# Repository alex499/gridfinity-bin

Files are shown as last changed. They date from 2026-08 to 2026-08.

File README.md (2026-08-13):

**English** · [Русский](README.ru.md)

# gridfinity-bin

A parametric [Gridfinity](https://gridfinity.xyz/) bin generator written from scratch in
OpenSCAD, with no external libraries.

**[Configure one in your browser →](https://alex499.github.io/gridfinity-bin/)** — no
install, no account. The page runs this same `gridfinity.scad` through OpenSCAD compiled to
WebAssembly, so the STL it hands you is the one the command line would produce.

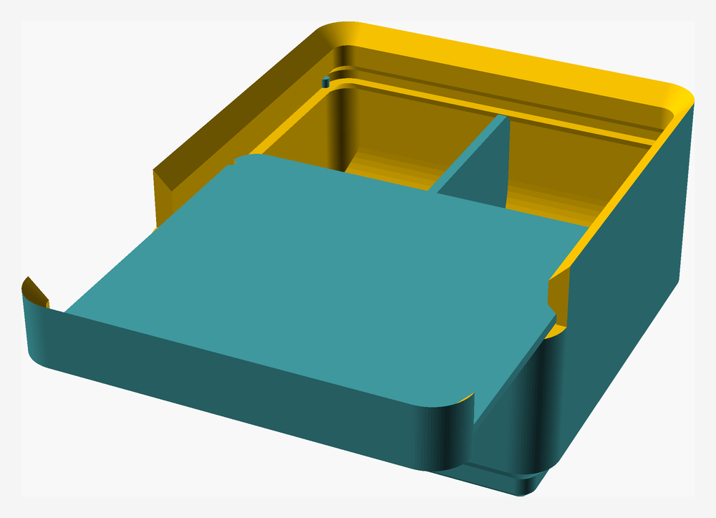
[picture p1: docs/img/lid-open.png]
A 1x1x3 bin with a two-by-two cell grid, its lid slid halfway out


*A 1x1x3 bin with `cells = 4`, its lid halfway out —
[open this one in the configurator](https://alex499.github.io/gridfinity-bin/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).
Every picture on this page is rendered from this file by
[scripts/render-images.sh](scripts/render-images.sh).*

This project is a compilation of three existing Gridfinity bin designs — it takes the
features of each and reimplements them as a single parametric model driven by the
OpenSCAD Customizer:

- [Gridfinity Bins medium size](https://www.printables.com/model/710839-gridfinity-bins-medium-size) by Plastic Flow
- [Gridfinity UltraLight Bins – Modular Clip-On Label System](https://www.printables.com/model/1481418-gridfinity-ultra-light-bins-modular-clip-on-label) by Muad'Dib
- [Gridfinity inserts with cover, divided in multiple ways](https://www.printables.com/model/665798) by mhejjas

The geometry was matched against the published STLs by measuring their cross-sections,
rather than by converting or editing the meshes. The scoop, for example, is a concave
fillet of radius 10 mm, tangent to both the inner front wall and the cavity floor —
numbers taken from the ultra-light bin's actual profile. Where the sources disagree
with the official Gridfinity dimensions, the spec wins: the stacking lip is built to
spec rather than copied from any of them.

## What is implemented

- Outer shell sized to the Gridfinity grid (42 mm pitch, 7 mm height unit) with rounded
  corners. Total height is `units_z * 7 + 4.4` mm, measured from the bottom of the feet —
  the feet are part of the height unit, not added on top of it
- Hollow interior with independent wall and floor thickness
- Full Gridfinity foot profile (0.8 mm chamfer / 1.8 mm vertical / 2.15 mm chamfer)
- Hollow feet, so the cavity extends down into the base and only a thin bottom skin
  remains — the "ultra light, no magnets" approach. The cavity inside a foot is a single
  taper rather than a copy of the stepped outer profile: less plastic and no horizontal
  overhang ledges to print
- Optional scoop: a concave fillet in the floor-to-front-wall corner, added as material
  inside the cavity, so its radius is never limited by wall or floor thickness
- Stacking lip to spec (0.7 / 1.8 / 1.9 mm, 4.4 mm total). Its bottom chamfer is derived
  from the wall thickness instead of being hard-coded: the spec's 0.7 mm assumes a 1.2 mm
  wall, and a thinner wall needs a longer run to avoid an unsupported ledge. With a plate
  under it that run starts lower still, so the same cone doubles as the slot's ceiling
- Optional flush front wall, padding the scoop side out to the lip's inner face so a
  swept-out part meets no ledge on the way to the rim
- A slot just under the lip that a closing plate slides into: the wall thickens 1.2 mm
  through a 45° ramp and steps back, and the step is the ledge the plate rests on. Nothing
  is built above it — the lip's own support cone is lowered onto the ceiling of the slot
  and is what holds the plate down. A round pin sunk into each side wall stands proud of it
  and the plate's edge snaps over it into a matching seat — 0.59 mm under a lid, 0.9 mm
  under a card, which is short and has nothing else gripping it
- Two plates use that slot, and `closure` picks between them. One is the clip-on label card,
  15 mm deep by default. The other is a **sliding lid** covering the whole bin. Same
  thickness, same ledge, same detents; the lid adds a tab that fills the mouth and restores
  the piece of lip it cut away, so a closed bin still stacks. Printed flat, the lid has no
  downward-facing face at all. On `auto` the bin decides for itself — card while it is
  undivided, lid once it is not, because a lid is the only thing that keeps contents from
  crossing between cells — but either plate can be asked for outright, and `none` leaves
  the bin open with no slot cut at all
- `split_lid` cuts the lid on the dividers between cells, one piece per cell, so a cell can
  be opened without pulling the whole lid off. Each piece slides into its own column through
  the same mouth and carries its slice of the tab. The divider under a seam becomes a rail
  and holds the two pieces on it the way a wall holds their outer edges: 1.2 mm of ledge
  under each edge, a cap 0.5 mm thick over it, and 45° flares into both so neither overhang
  needs support. The cap tops out level with the lid rather than with the rim, and the edge
  under it is chamfered on the same 45° to nest below it, so the closed lid is flat — nothing
  of the rail stands above it. The rail carries the same detent the walls do, one in each of
  its two grooves, so every piece snaps over a pair of pins just as the whole lid snaps over
  the pair in the walls. With two rows the bin gets a second mouth, in the back wall, so each
  row slides in from its own end — which is why a rail lying across the bin can keep its cap:
  no piece ever has to travel over one. There are always as many pieces as there are cells
- Dividers: `cells` is the whole layout, as one number — how many compartments the inside is
  split into. Two sit side by side, with the divider running the full depth; three put a row
  of two in front of a single one; four is two by two. They stop 0.2 mm below the ledge so
  the lid slides over them, and carry nothing themselves unless a seam lands on them — that
  is what moving to a lid buys. Every row gets the front wall's scoop grown from its own
  outer wall — the front row from the front, the back row from the back — so each row is a
  little bin of its own, facing its own end; it is clamped to the row depth.
  See [docs/slot-profile.md](docs/slot-profile.md) for the measured sections

| | |
|---|---|
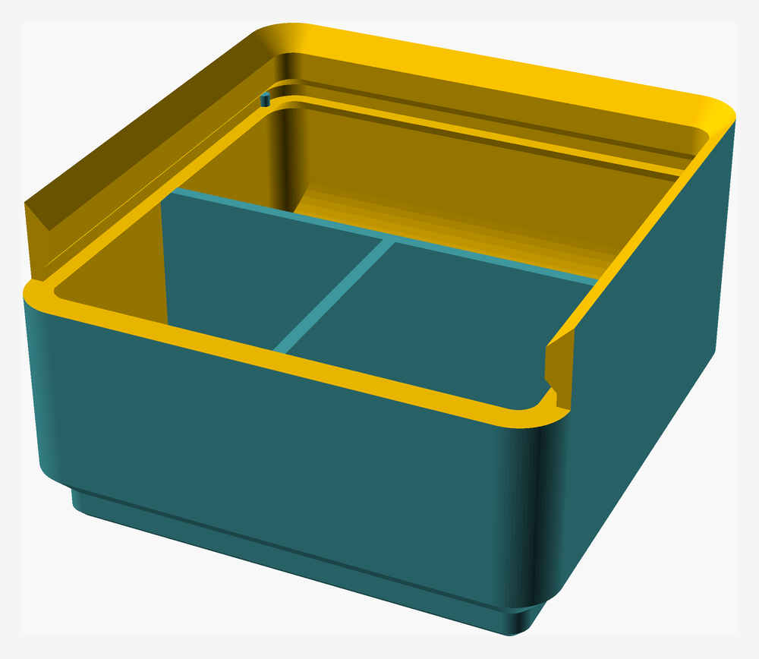
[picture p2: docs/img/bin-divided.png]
The same divided bin with the lid off
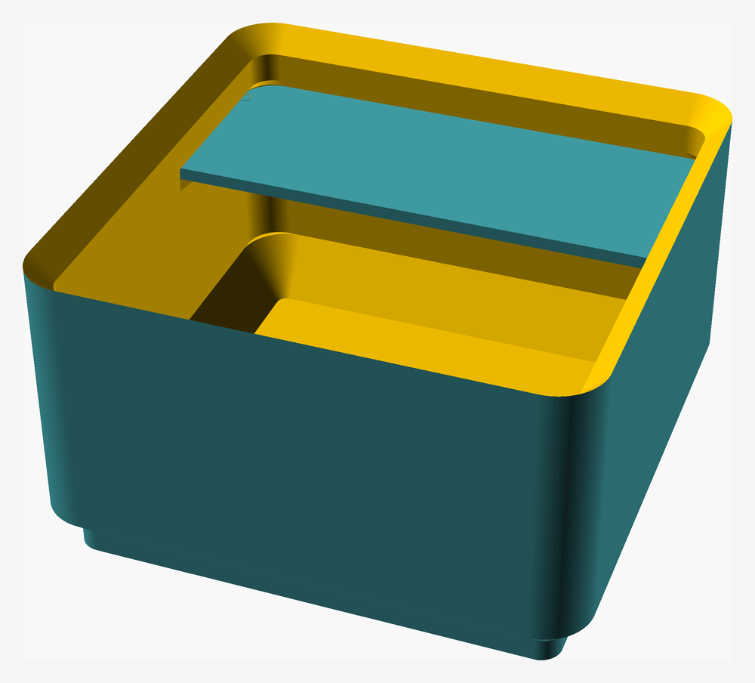
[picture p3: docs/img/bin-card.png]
An undivided 1x1x3 bin with its label card in the slot
|  |  |
| `cells = 3`, lid off: a row of two in front of a single cell, each row scooped from the divider in front of it. The notch in the front wall is the mouth the lid slides through. | Undivided, so the same slot holds a label card instead, and the front wall is left whole. |

## Not implemented yet

- Magnet and screw holes

## Usage

Open in the GUI and use the Customizer panel:

```sh
openscad gridfinity.scad
```

Render an STL:

```sh
openscad -o bin.stl gridfinity.scad
```

Override parameters without editing the file:

```sh
openscad -o bin_1x1x3.stl -D 'units_x=1' -D 'units_y=1' -D 'units_z=3' gridfinity.scad
```

[`scripts/render-stl.sh`](scripts/render-stl.sh) renders a ready-to-print set into `stl/`:
every `cells` and closure combination of the 1x1x3, with its cards and lids. The files are
not in git — run the script after changing the model.

```sh
./scripts/render-stl.sh
```

## The browser configurator

[`web/`](web/) is a static page that renders this file in the browser: OpenSCAD itself,
compiled to WebAssembly, driven by the same `-D` flags you would type. There is no server
and nothing is uploaded — the model is fetched as plain text and rendered locally, taking
about 0.4 s for a 2x2x3 bin and under 3 s for the largest one the sliders allow.

The address bar always carries the whole configuration, so a link reproduces a bin exactly:
copy it to send someone a design, or bookmark it and let the browser sync it to the machine
next to the printer. Every parameter is written out rather than only the ones that differ
from a default, so an old link cannot quietly change meaning when a default does.

```sh
cd web
yarn install
yarn serve      # builds _site/ and serves it on http://localhost:8080
```

`node verify.js` checks the page against the CLI: it drives the real worker, compares signed
volume and bounding box for a spread of configurations, and sweeps every
`cells` x `split_lid` x `closure` x `part` combination for a clean render. The sweep alone
(`node verify.js sweep`) needs no OpenSCAD installed and is what CI runs before deploying.

Editing `gridfinity.scad` needs no change here — the page reads it at run time. Only a *new*
parameter needs a control adding to `web/index.html`.

The page opens on a 1x1x3 bin. The defaults in the table below are the file's own, which is
what the CLI gives you; the two are deliberately allowed to differ.

## Parameters

| Parameter | Default | Range | Meaning |
|---|---|---|---|
| `units_x`, `units_y` | 2 | 1–10 | Bin footprint in 42 mm grid units |
| `units_z` | 3 | 1–10 | Bin height in 7 mm units |
| `wall_thickness` | 1 | 0.4–5 | Side wall thickness |
| `floor_thickness` | 1 | 0.4–5 | Thickness of the flat floor above the feet |
| `solid_foot` | false | bool | Fill the feet in instead of letting the cavity dip into them |
| `scoop` | true | bool | Enable the front scoop fillet |
| `scoop_flush` | false | bool | Pad the scoop-side wall out to the lip's inner face |
| `closure` | auto | auto, card, lid, none | Which plate the slot is cut for; `auto` is a card until the bin is divided, then a lid, and `none` leaves the bin open with no slot |
| `cells` | 1 | 1–4 | Compartments the inside is split into; 2 side by side, 3 a row of two in front of one, 4 two by two |
| `split_lid` | false | bool | Cut the lid into one piece per cell, each sliding in from its own end |
| `part` | bin | bin, card, lid, assembled | Which piece to render; `assembled` shows the bin with its plate in place |
| `card_length` | 15 | 5–40 | How deep the label card runs in from the back wall; the ledge follows it |
| `split` | false | bool | Debug: cut the model open to inspect the cross-section |
| `split_axis` | x | x, y, xy | Debug: which plane the cut runs on; `xy` leaves a quarter |

`scoop_radius` (default 10 mm) is currently in the hidden group; move it out of
`/* [Hidden] */` to expose it in the Customizer.

A note on `wall_thickness`: it sets the side walls, and the same value is used as the
skin left inside the feet. Because the foot cavity is a single taper, that skin is
thinner than `wall_thickness` where the taper passes closest to the outer surface —
0.69 mm at the default of 1 mm. Raise `wall_thickness` if your nozzle needs more.

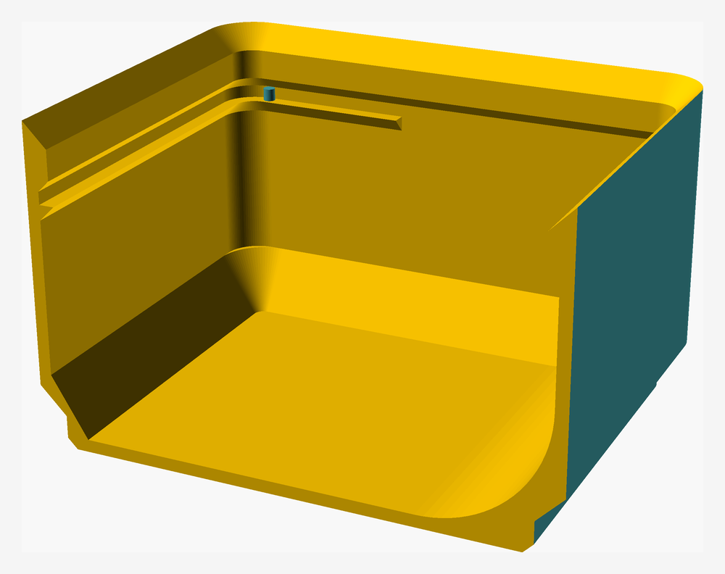
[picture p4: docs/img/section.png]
A 1x1x3 bin cut open, showing the scoop, the slot and a detent


*`split = true` cuts the model open. Visible here: the scoop sweeping up the front wall, the
slot running around under the rim with its ledge, and one of the two detents — the small pin
in the side wall that the plate snaps over.*

## Cards and lids

Both are generated by the same file, with the same `units_*` and `cells` you used for the
bin:

```sh
openscad -o card.stl -D 'units_x=1' -D 'units_y=1' -D 'part="card"' gridfinity.scad
openscad -o lid.stl  -D 'units_x=1' -D 'units_y=1' -D 'cells=4' \
                     -D 'part="lid"' gridfinity.scad
```

Print whichever one the bin was built for — that is `closure`, and on `auto` it follows the
layout. Both are per bin size — a card for a 1x1 will not span a 2x2 — and with `split_lid`
the lid follows the layout too, coming out as one piece per cell. The pieces are already
laid out, coplanar and a gap apart, so one render is the whole set.

`part = "assembled"` puts the plate back where it sits in the bin and renders both. It picks
whichever plate the slot was cut for, and is for looking at rather than printing:

```sh
openscad -D 'units_x=1' -D 'units_y=1' -D 'cells=4' \
         -D 'part="assembled"' gridfinity.scad
```

Nothing about the plate is copied from the UltraLight Bins card. That model recesses its
groove 2.0 mm into the wall; here the slot's floor is the wall face, so the plate spans the
full opening. Its plate is 0.8 mm thick; here it is 1.0, and the slot is not a measured
number at all — it is `plate_thickness + plate_play`, so the plate always fits and whatever
is left over is exactly how far it can float before the lip's cone catches it. That play is
0 by default, so the slot is the plate. A 1x1 card therefore comes out 39.3 x 15 x 1.0
rather than 37.4 x 11.95 x 0.8: more label area, and not interchangeable with that model's
cards.

The sliding lid, the free divider grid and the round detent come from [Gridfinity inserts
with cover, divided in multiple ways](https://www.printables.com/model/665798) by mhejjas,
measured the same way.

## Credits

- **Gridfinity** is a storage system designed by
  [Zack Freedman](https://www.youtube.com/@ZackFreedman). This project is an independent
  implementation of the format, not affiliated with him.
- **Gridfinity Bins medium size** by **Plastic Flow** — licensed CC BY 4.0 —
  <https://www.printables.com/model/710839-gridfinity-bins-medium-size>
  (itself a remix of Zack Freedman's Divider Bins)
- **Gridfinity UltraLight Bins – Modular Clip-On Label System** by **Muad'Dib** —
  licensed CC BY-NC-SA 4.0 —
  <https://www.printables.com/model/1481418-gridfinity-ultra-light-bins-modular-clip-on-label>
- **Gridfinity 1 x 1 x 2 and 1 x 1 x 3 inserts with cover, divided in multiple ways** by
  **mhejjas** — licensed CC BY 4.0 — <https://www.printables.com/model/665798>
  (the sliding lid, the free divider grid and the round detent)

## License

**CC BY-NC-SA 4.0** — [Attribution–NonCommercial–ShareAlike 4.0 International](https://creativecommons.org/licenses/by-nc-sa/4.0/)

This is not a free choice. One of the three source designs (UltraLight Bins by Muad'Dib)
is published under CC BY-NC-SA 4.0, whose ShareAlike term requires derivative works to
carry the same license, and whose NonCommercial term forbids commercial use. The other two
sources (both CC BY 4.0) are compatible with being combined into that. So the combined
result cannot be released under anything more permissive.

In practice this means:

- attribution to the authors above is required
- no commercial use
- remixes must stay under CC BY-NC-SA 4.0

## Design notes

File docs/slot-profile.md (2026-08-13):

# The slot, and the two plates that live in it

One slot, one profile, two plates. A short plate is the clip-on label card; a full-length one
is the sliding lid. Same thickness, same ledge, same detents — only the depth differs, and the
lid carries a tab at the front.

The bin picks between them: an undivided bin gets the card, a divided bin gets the lid, because
a lid is the only way to keep contents from crossing between cells when the bin is tipped.

## The profile

Cross-section in Y-Z through a side wall: wall on the right, cavity on the left. Horizontal
scale 0.1 mm per character, vertical 0.2 mm per line, so the proportions are roughly true. The
`abs` column is z in the model for a 3u bin; numbers are for the defaults, `wall_thickness = 1`.

```
   z     abs                      cavity │ wall
       17.25        ▒▒▒▒▒▒▒▒▒▒▒▒▒▒▒▒▒▒▒
       17.05        ▒▒▒▒▒▒▒▒▒▒▒▒▒▒▒▒▒▒▒    lip inner face
       16.85        ▒▒▒▒▒▒▒▒▒▒▒▒▒▒▒▒▒▒▒
       16.65        ▒▒▒▒▒▒▒▒▒▒▒▒▒▒▒▒▒▒▒
       16.45        ▒▒▒▒▒▒▒▒▒▒▒▒▒▒▒▒▒▒▒
       16.25        ▒▒▒▒▒▒▒▒▒▒▒▒▒▒▒▒▒▒▒  ╮ lip cone         45°, and what holds the plate
       16.05          ▒▒▒▒▒▒▒▒▒▒▒▒▒▒▒▒▒  │
       15.85            ▒▒▒▒▒▒▒▒▒▒▒▒▒▒▒  │                  not part of the slot, but it
       15.65              ▒▒▒▒▒▒▒▒▒▒▒▒▒  ╯                  starts where the slot ends
 2.0   15.45  ░░░░░░░░░░░░░░░▒▒▒▒▒▒▒▒▒▒  ← ceiling of the slot, and the top of the plate
 1.9   15.35  ░░░░░░░░░░░░░░░▒▒▒▒▒▒▒▒▒▒  ╮
 1.7   15.15  ░░░░░░░░░░░░░░░▒▒▒▒▒▒▒▒▒▒  │ slot       1.0   floor = the wall face itself
 1.5   14.95  ░░░░░░░░░░░░░░░▒▒▒▒▒▒▒▒▒▒  │
 1.3   14.75  ░░░░░░░░░░░░░░░▒▒▒▒▒▒▒▒▒▒  │                  ░ = the plate, 1.0 thick
 1.1   14.55  ░░░░░░░░░░░░░░░▒▒▒▒▒▒▒▒▒▒  ╯
 0.9   14.45        ▒▒▒▒▒▒▒▒▒▒▒▒▒▒▒▒▒▒▒  ← the ledge, 0.9 proud of the wall face
 0.7   14.15          ▒▒▒▒▒▒▒▒▒▒▒▒▒▒▒▒▒  ╮
 0.5   13.95            ▒▒▒▒▒▒▒▒▒▒▒▒▒▒▒  │ ramp       0.9   45°, thickening the wall
 0.3   13.75              ▒▒▒▒▒▒▒▒▒▒▒▒▒  │
 0.1   13.55                ▒▒▒▒▒▒▒▒▒▒▒  ╯
 0.0   13.45  ┄┄┄┄┄┄┄┄┄┄┄┄┄┄┄▒▒▒▒▒▒▒▒▒▒  ← wall face, nothing below this is slot
```

The wall thickens by `slot_ledge` through a 45° ramp and then steps back, and that step is the
ledge. The slot's floor *is* the wall face, so there is no groove depth to measure from — the
plate simply spans the opening and overlaps the ledge by 0.7 a side.

Nothing is built above the slot. The plate is held down by the lip's own 45° support cone,
which is lowered to land exactly on the ceiling of the slot.

`slot_ledge` = 0.9 is the largest ledge that stays inside the lip: any more and it would stand
proud of the lip's inner face. Every sloped face is 45° or shallower, so nothing in the slot
prints as an unsupported overhang.

## How much the plate can lift

Nothing presses the plate onto the ledge, so it floats until its outer top corner wedges into
the cone. There is no flat ceiling to stop it earlier: over the middle of the plate the bin is
open all the way to the rim, and the cone only comes down at the walls.

```
travel = slot_height - plate_thickness + plate_gap/2
```

The last term is the side clearance arriving through a 45° ramp: the corner sits `plate_gap/2`
in from the wall face, and the cone needs exactly that much height to reach it. At 1.0, 1.0
and 0.4 the travel is 0.2 — measured on the render as 0.216, and it tracks the formula to the
0.01 across thicknesses.

The plate is 1.0 rather than the 0.8 of the card it descends from for this reason alone: at
0.8 the travel was 0.42, and the plate would knock against the foot of a stacked bin. 1.2 is
the hard limit, where the corner touches the cone at rest and the plate no longer slides.

Chamfering the plate's edge to follow the cone — which is what the reference does — does not
help here. The travel is decided at the outer top corner, and a chamfer runs inward from that
corner without moving it. What it would buy is thickness in the middle, for stiffness, and
even that is capped: the foot of a stacked bin comes down to 15.90.

## Where the slot hangs

`slot_top(nz)` is `body_top(nz) - slot_drop`, and everything hangs down from there.
`slot_drop` = 0.8 is the one free number: it sets how far below the rim the plate sits. Lower
it and the plate goes with it.

## Numbers that follow

| | |
|---|---|
| ledge, top face | 14.45 |
| plate | 14.45 → 15.45 |
| ceiling of the slot | 15.45 |
| top of the dividers | 14.25, or 16.25 with `closure = none` — nothing slides over them |
| card | 39.1 × 11.95 × 1.0 |
| lid, 1x1 | 41.49 × 40.3 × 6.2 |

## The detent

A round pin, Ø0.95, sunk into each side wall so that only part of it shows: its axis sits
0.115 outside the wall face, leaving it 0.59 proud into the slot. It runs the full height of
the slot. The plate has a matching seat cut with the same circle plus 0.05, so the pin drops
in with a little slop but no rattle.

The plate's edge stands 0.2 in from the wall face, so getting past the pin costs 0.39 a side.
That is the snap, and it is paid once, at the very end of travel — the seat is centred 3.05 in
from the back wall, where the plate stops.

Sinking the pin rather than standing it on the face is the point: what the plate's edge meets
is a curve it can ride up, not a corner it has to jump. Taken from the reference, whose
numbers these are; the card and the lid share both the pin and the seat, so either part snaps
into the same place.

## The mouth, and why it is exactly `corner_radius` deep

A lid can only be as wide as the narrowest point on its way in, and the way in is narrowed by
the rounded corners. So the front wall, the front of the lip and both front corners are cut
away from the ledge up — that cut is the mouth.

Cut it exactly `corner_radius` deep and both corner arcs disappear completely, leaving a
straight-sided channel at the full width of the cavity. This is exact, not a fit: the inner arc
ends at

```
inner_y/2 − inner_r = (outer_y/2 − w) − (corner_radius − w) = outer_y/2 − corner_radius
```

which is where the outer arc ends too, whatever the wall thickness. Measured on the render, the
opening is 19.75 half-width at every y from the mouth back, and the plate's back corners come
out concentric with the cavity's with 0.2 all round.

Only the back corners are rounded, and only because they have to follow the cavity. A card's
front edge stands in open cavity with nothing to follow, so it stays square and keeps the label
area. A lid's front edge is at the bin's outer face, so it takes the bin's own outer radius.

The reference this came from cuts 3.5 at a radius of 3.75 — the same place, to 0.25.

Consequence: with no lid inserted the lip is interrupted over 3.75 of 41.5 at the front, so a
bin stacked on top is unsupported there. The tab restores it, which means a divided bin stacks
properly only with its lid closed.

## The tab

The tab is the piece of wall and lip the mouth cut away, carried on the lid. Its outer face is
the bin's own outer surface, so it matches exactly, and its top lands on the lip top, 20.65,
never above.

Its inner face is *not* the bin's. On the bin the lip stands on a 45° cone that bridges it down
to the wall; the tab runs straight down at the lip's inner face instead. Copying the cone would
have left the lid with 44 mm² of 45° overhang hanging over its own plate, and it buys nothing —
the space under it is empty slot, in front of the mouth, where the plate does not reach.

The lid prints flat, plate down, and with that change it has **no downward-facing face above
the bed at all** — measured, not assumed.

## Dividers

Dividers stop 0.2 below the ledge, so the lid passes over them, and they carry nothing: no
rail, no ledge, no chamfer. That is the whole point of moving to a lid — once nothing has to be
held at the top of a cell, cells can be laid out freely.

Every row carries the front wall's scoop, grown from its own outer wall: the same quarter
round, `scoop_radius` = 10, tangent to the floor and to that wall. The front row sweeps against
the bin's front wall, the back row against the back wall — the same shape mirrored — so each row
is a little bin of its own facing its own end, which is also the end its lid piece slides in by.

It is clamped to the row depth, so cutting a bin into shallow rows does not ask for a scoop
deeper than the row. The dividers get nothing, and neither do the side walls: at a wall the
cavity runs on into the hollow foot, and that is already a 4.75 mm taper reaching 2.91 mm in.

`cells` is the whole layout as one number: 1 leaves the inside whole, 2 splits it side by
side, 3 puts a row of two in front of a single cell, 4 is two by two. Rows run across X and
are counted from the front, rows are equal in height and cells equal in width within their
row, so `cells = 3` on a 1x1 gives a front row of two 19.25 cells and a back row of one
39.5 cell, both 19.25 deep.

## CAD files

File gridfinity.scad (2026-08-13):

/* [Bin size] */
units_x = 2;   // [1:10]
units_y = 2;   // [1:10]
units_z = 3;   // [1:10]

/* [Walls] */
wall_thickness = 1;    // [0.4:0.1:5]
floor_thickness = 1;   // [0.4:0.1:5]
// fill the feet in instead of letting the cavity dip into them
solid_foot = false;
scoop = true;
scoop_flush = false;
// which plate the slot is cut for; auto is a card until the bin is divided, then a lid,
// and none leaves the bin open with no slot at all
closure = "auto";   // [auto, card, lid, none]

/* [Dividers] */
// how many cells to split the inside into: 2 side by side, 3 a row of two in front of a
// single one, 4 two by two
cells = 1;   // [1:4]
// cut the lid into one piece per cell, each sliding in from its own end of the bin
split_lid = false;

/* [Output] */
part = "bin";      // [bin, card, lid, assembled]
// how deep the label card runs in from the back wall, and how far the ledge follows it
card_length = 15;   // [5:0.05:40]

/* [Debug] */
split=false;
split_axis = "x";   // [x, y, xy]

/* [Hidden] */
grid_unit = 42;
unit_height = 7;
corner_radius = 7.5 / 2;
clearance = 0.5;
scoop_radius = 10;
$fn = 92;

// foot profile (bottom to top)
foot_bottom_chamfer = 0.8;
foot_vertical = 1.8;
foot_top_chamfer = 2.15;
foot_height = foot_bottom_chamfer + foot_vertical + foot_top_chamfer;

foot_mid_radius  = 3.2 / 2;
foot_base_radius = 1.6 / 2;

// The plate: a card when it is short, a sliding lid when it runs the whole bin.
plate_thickness = 1;
plate_play      = 0;             // how far it floats in the slot before the lip's cone catches it
plate_gap       = 0.2;           // its clearance in the slot, 0.1 a side
lid_notch       = corner_radius; // depth of the mouth; see docs, this value is not free
lid_cap         = 0.5;           // how much of a piece's edge a rail holds over it; also its thickness

// Slot the closing plate sits in, just under the lip. The wall thickens by slot_ledge
// through a 45 deg taper and then steps back, and the step is the ledge. See docs.
slot_ledge  = 1.2;   // how far the ledge stands proud of the face it grows out of, wall or rail
slot_height = plate_thickness + plate_play;   // the slot, floor to ceiling
slot_drop   = 0.8;   // ceiling of the slot below the rim; the one number setting plate height

// Detents on the side walls that the plate's edges snap over: a round pin sunk into the
// wall face, so what the plate meets is a curve rather than a corner.
slot_detent_radius = 0.475;
slot_detent_proud  = 0.59;   // how far it stands into the slot, more than its own radius
card_detent_proud  = 0.9;    // a card is short and gripped by nothing else, so its catch is deeper
slot_detent_offset = 3.05;   // its centre, measured in from the back wall

divider_thickness = wall_thickness;

// stacking lip profile (bottom to top)
lip_bottom_chamfer = 0.7;
lip_vertical       = 1.8;
lip_top_chamfer    = 1.9;
lip_height = lip_bottom_chamfer + lip_vertical + lip_top_chamfer; // 4.4

// 45 deg cone bridging the wall up to the lip. Spec's 0.7 assumes a 1.2mm wall;
// for thinner walls the excess goes below body_top.
function lip_support() = max(0, lip_top_chamfer - wall_thickness);
function lip_extra()   = max(0, lip_support() - lip_bottom_chamfer);

// footprint of a single foot at its three levels, inset from the outer surface
function foot_top(inset)  = grid_unit - clearance - 2*inset;
function foot_mid(inset)  = foot_top(inset) - 2*foot_top_chamfer;
function foot_base(inset) = foot_mid(inset) - 2*foot_bottom_chamfer;

// outer dimensions of the bin
function outer_x(nx) = grid_unit * nx - clearance;
function outer_y(ny) = grid_unit * ny - clearance;
function body_top(nz) = unit_height * nz - foot_height;

// cross-section at a given depth from the outer surface
function inset_x(nx, d) = outer_x(nx) - 2*d;
function inset_y(ny, d) = outer_y(ny) - 2*d;
function inset_r(d)     = corner_radius - d;

// dimensions of the inner cavity
function inner_x(nx) = inset_x(nx, wall_thickness);
function inner_y(ny) = inset_y(ny, wall_thickness);
function inner_r()   = inset_r(wall_thickness);

// inner surfaces the scoop is tangent to
function wall_y(ny)  = -inner_y(ny)/2;          // front wall, inner face
// cavity floor: inside the foot, or on top of it once the foot is filled in
function floor_z()   = solid_foot ? floor_thickness : -foot_height + wall_thickness;
// flush pads out to the lip's inner face, what stands furthest in above the scoop. A lid's
// mouth takes the lip and the ledge with it, so there is nothing left to pad out to.
function scoop_wall()     = !scoop_flush || lidded() ? wall_thickness : lip_top_chamfer;
function scoop_wall_y(ny) = -outer_y(ny)/2 + scoop_wall();

// The slot hangs from its ceiling, which is where the lip's cone starts: that cone is what
// holds the plate down, so nothing has to be built above the slot.
function slot_top(nz)   = body_top(nz) - slot_drop;
function ledge_top(nz)  = slot_top(nz) - slot_height;
function ledge_bot(nz)  = ledge_top(nz) - slot_ledge;
function ledge_depth()  = wall_thickness + slot_ledge;

// centre of the detent pin: sunk into the wall face by the part of it that does not show
function detent_proud() = lidded() ? slot_detent_proud : card_detent_proud;
function detent_x(nx)   = inner_x(nx)/2 - detent_proud() + slot_detent_radius;
// A piece snaps over a pin near the end of its own travel: the back wall when its row is the
// only one, the seam between rows when there are two. Rows are given in their own frame, the
// one the row is built in, so both rows read the same number.
function detent_y(ny)   = seamed() && two_rows() ? -(seam_face() + slot_detent_offset)
                                                 : inner_y(ny)/2 - slot_detent_offset;

// the plate stops against the back wall; the lid runs on from there to the outer face
function plate_back(ny) = inner_y(ny)/2 - plate_gap/2;
function lid_depth(ny)  = plate_back(ny) + outer_y(ny)/2;
function mouth_y(ny)    = -outer_y(ny)/2 + lid_notch;

// Compartments. cells is the whole layout: one cell, two side by side, three as a row of
// two in front of a single one, four as two by two. Rows run across X, counted from the
// front, and row_list()[i] is how many cells the i-th row holds.
function row_list()  = cells >= 4 ? [2, 2]
                     : cells >= 3 ? [2, 1]
                     : cells >= 2 ? [2]
                     :              [1];
function row_count() = len(row_list());
function row_n(i)    = row_list()[i];
function divided()   = cells > 1;

// whether the bin is closed by anything at all; none leaves it open and skips the slot
function covered() = closure != "none";

// which plate the slot is built for. Only a lid gets a mouth, a ledge round the whole
// perimeter and a tab; a card gets a ledge card_length long and an unbroken front wall
function lidded() = covered() && (closure == "lid" || (closure == "auto" && divided()));

function row_h(ny)        = (inner_y(ny) - (row_count()-1)*divider_thickness) / row_count();
function row_y0(ny, i)    = -inner_y(ny)/2 + i * (row_h(ny) + divider_thickness);
function cell_w(nx, i)    = (inner_x(nx) - (row_n(i)-1)*divider_thickness) / row_n(i);
function divider_x(nx, i, j) = -inner_x(nx)/2 + j*(cell_w(nx,i) + divider_thickness) - divider_thickness/2;
// 0.2 clear of the plate sliding over it; with no plate it runs up to the top of the body
function divider_top(nz)  = covered() ? ledge_top(nz) - 0.2 : body_top(nz);

// A divider that runs the full depth of the bin lies along the way the lid slides, so the
// lid can be cut on it: one piece per cell, each going into its own column on its own. The
// divider becomes a rail and holds the two pieces meeting on it exactly the way a wall holds
// their outer edges — a groove down either face, capped by a top that is flush with the rim.
// Two rows split the inside evenly, so the seam between them is the centreline and the back
// row is the front one mirrored in Y. Each row goes in through its own mouth, which is why a
// rail across the bin can keep its cap: no piece ever has to travel over one.
function seamed()    = split_lid && lidded() && cells > 1;
function two_rows()  = row_count() > 1;
function seam_face() = divider_thickness/2;              // the cross rail's face, at y = 0
function seam_edge() = seam_face() + plate_gap/2;        // where a piece stops against it
function ledge_w()     = divider_thickness + 2*slot_ledge;   // the rail under the pieces
function rail_w()      = divider_thickness + 2*lid_cap;    // and the cap over them
function groove_h()    = slot_height - lid_cap;

// Every rail carries the same detent the walls do, one in each of its two grooves, so each
// piece snaps over a pair of them just as the whole lid snaps over the pair in the walls.
function rail_detent_x(nx, i, j, s) = divider_x(nx, i, j)
                                      + s*(divider_thickness/2 + slot_detent_proud
                                           - slot_detent_radius);
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

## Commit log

2026-07-30 Gridfinity bin generator on OpenSCAD
    [gridfinity.scad]
2026-07-30 Add stacking lip, fix bin height, simplify foot cavity
    [gridfinity.scad]
2026-07-30 Add clip-on label rail
    [gridfinity.scad]
2026-08-01 Extend the label groove forward and chamfer the upper rib
    [gridfinity.scad]
2026-08-03 Replace the label rail with a slot, add a sliding lid and a cell grid
    [gridfinity.scad]
2026-08-03 Keep reference material in reference/, ignore the Customizer preset
2026-08-04 Scoop the back face of every row divider
    [gridfinity.scad]
2026-08-05 Add a flag to fill the feet in instead of hollowing them
    [gridfinity.scad]
2026-08-05 Add a flag to cut the lid into one piece per cell
    [gridfinity.scad]
2026-08-05 Cut with split whichever part is selected, not only the bin
    [gridfinity.scad]
2026-08-05 Hold a split lid's seam in a grooved rail, with no gap beside it
    [gridfinity.scad]
2026-08-05 Add an axis to split, so it cuts on x, y or both
    [gridfinity.scad]
2026-08-05 Sink the rail's cap flush with the lid it holds down
    [gridfinity.scad]
2026-08-05 Give every rail the wall's detent, one in each groove
    [gridfinity.scad]
2026-08-09 Size the slot from the plate it holds, and the flush pad from the slot
    [gridfinity.scad]
2026-08-09 Let the bin be asked for a card or a lid, not only guess
    [gridfinity.scad]
2026-08-10 Take the float out of the slot and deepen the card's catch
    [gridfinity.scad]
2026-08-10 Ask for cells by number, and give every row its own end of the bin
    [gridfinity.scad]
2026-08-12 Take the ledge out of the mouth and run the side ones straight into the wall
    [gridfinity.scad]
2026-08-13 Fold cover into closure, so an open bin is one of the plates you pick
    [gridfinity.scad]
2026-08-13 Run the dividers up to the rim when nothing slides over them
    [gridfinity.scad]
